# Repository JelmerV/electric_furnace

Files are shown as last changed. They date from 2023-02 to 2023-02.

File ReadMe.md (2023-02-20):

# Electronic furnace controller

This project contains the source code for the controller of an electric furnace, cad files for the enclosure, and some images of the system.

This is an arduino sketch for the controls of an electric furnace/foundry. It uses a K type thermocouple in combination with a MAX6675 IC to check the temperature inside the furnace. Current temperature and the target temperature are displayed on a small 128x64 oled display. An encoder can be used to change the target temperature. 2 relays are used to which the 220V on the heating coils. It switches both wires to ensure there is no live voltage on the coils. 2 switches are used to monitor when the lid gets lifted, in which case the voltage is immediately switched off. This is also indicated on the display by the icon of an open door. Whenever the heating elements are powered, a flaming icon is displayed.

## Wiring

The microcontroller used is an arduino nano. Both relays are controlled by a single output signal. The door switches are wired in series, using the normally closed contact. I am using a small 220vAC-5vDC converter to get the 5v for the arduino. The encoder is attached at pins 2 and 3 for external interrupts. The display uses pins A4 and A5 for SPI communication.

## Libraries

This is a platformio project, so you should be able to just open this in vs code if you have the platformio extension. If you want to use the arduino ide, then you will need to manually install the required libraries. The source code is [here](./Code/electric_furnace/src/main.cpp), and should also work as ini file. The required libraries are:

* Adafruit_GFX (for the graphics)
* Adafruit_SSD1306 (for the mini oled display)
* Adafruit max6675 (for reading the thermocouple)

## hardware

My furnace is made of firebricks and aerated concrete blocks. I used kanthal A1 wire to wind some coils totaling around 18 ohm, so at 220v it pulls around 12 amps, so 2600 Watts. THe 3d printed electronics enclosure is mounted on the side. The final system can be seen in the following image:

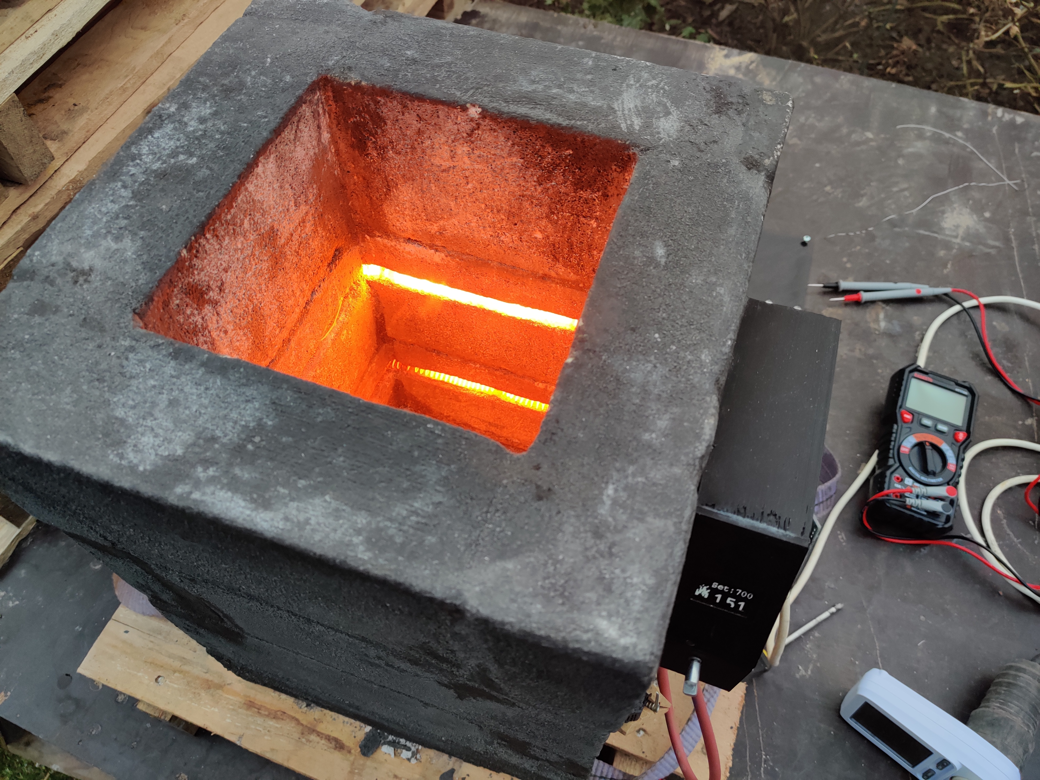
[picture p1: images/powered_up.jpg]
final system


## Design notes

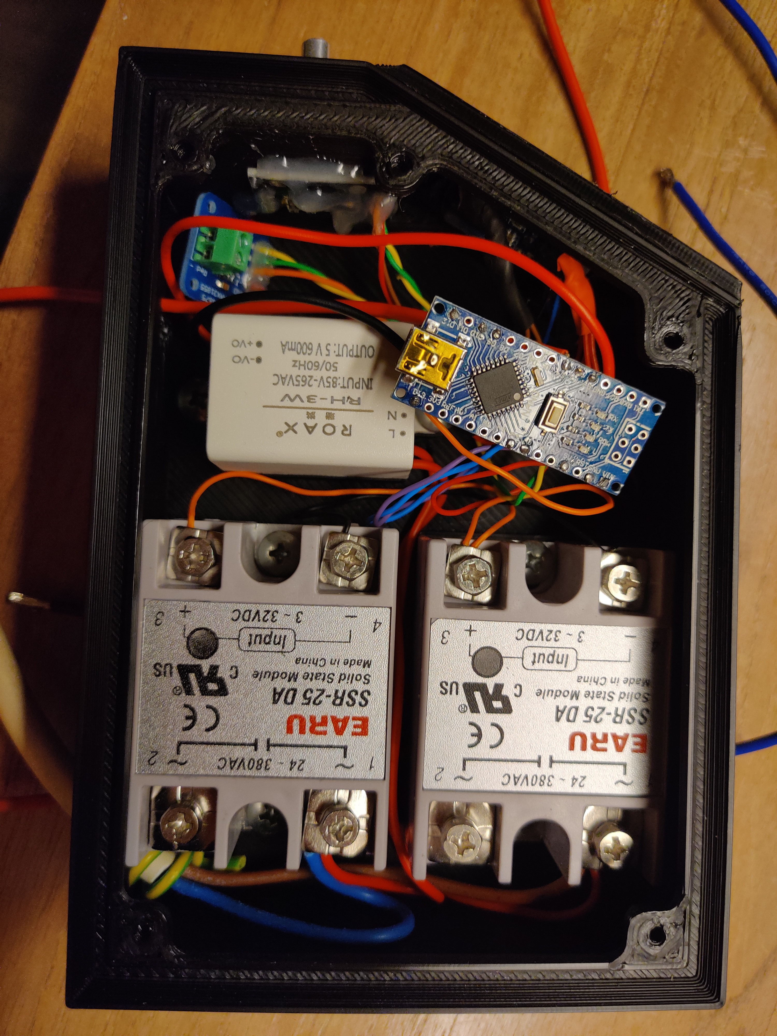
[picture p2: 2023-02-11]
images/electronics.jpg

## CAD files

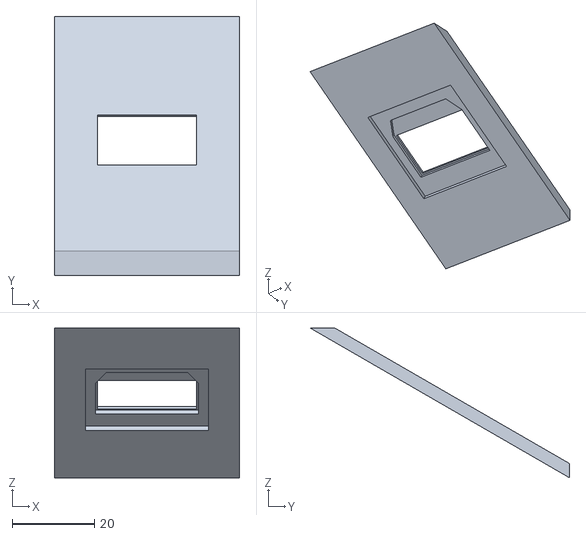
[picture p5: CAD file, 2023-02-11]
CAD/screenplate.STL
45.0 x 63.0 x 36.4

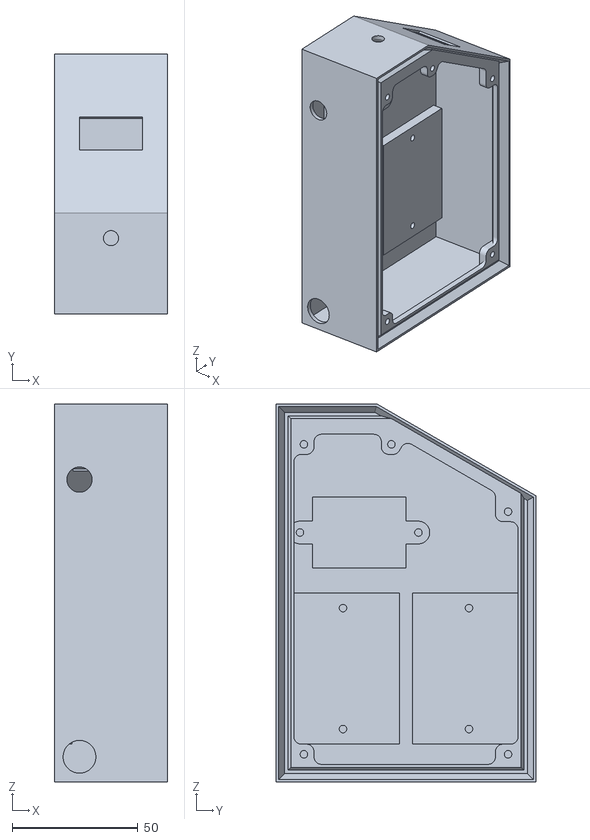
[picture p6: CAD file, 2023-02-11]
CAD/electronics box base.STL
45.0 x 103.0 x 150.0

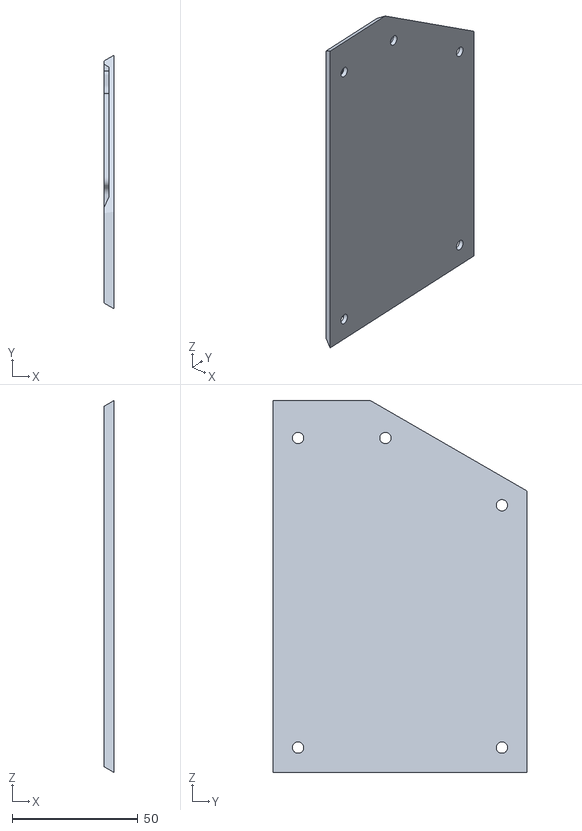
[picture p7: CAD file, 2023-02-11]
CAD/electronics box lid.STL
4.00 x 100.8 x 147.8

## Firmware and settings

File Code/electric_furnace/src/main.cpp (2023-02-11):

#include <Adafruit_GFX.h>
#include <Adafruit_SSD1306.h>
#include <Fonts/FreeMonoBold12pt7b.h>
#include <Fonts/FreeMonoBold24pt7b.h>  // Add a custom font
#include <SPI.h>
#include <Wire.h>

#include "Arduino.h"
#include "max6675.h"

// io
#define PIN_DOOR_IN 4    // Door switches input
#define PIN_COIL_OUT 13  // Coil relay control
#define PIN_ENCODER_A 2  // encoder function only works for port C, pins 0-7
#define PIN_ENCODER_B 3
#define ENCODER_PIN_MASK (1 << PIN_ENCODER_A | 1 << PIN_ENCODER_B)

// screen config
#define SCREEN_ADRESS 0x3C  // I2C address (pins A4, A5)
#define SCREEN_WIDTH 128    // OLED display width, in pixels
#define SCREEN_HEIGHT 64    // OLED display height, in pixels
#define OLED_RESET -1       // Reset pin # (or -1 if sharing Arduino reset pin)
Adafruit_SSD1306 display(SCREEN_WIDTH, SCREEN_HEIGHT, &Wire, OLED_RESET);

// thermometer config
int thermoDO = 12;
int thermoCS = 9;
int thermoCLK = 10;
MAX6675 thermocouple(thermoCLK, thermoCS, thermoDO);

// 'flame_icon', 29x43px
const unsigned char flame_icon[] PROGMEM = {
    0x00, 0x70, 0x0e, 0x00, 0x00, 0x70, 0x0e, 0x00, 0x00, 0x60, 0x0e, 0x00, 0x00, 0x01, 0xf0, 0x00, 0x00, 0x03, 0xf0, 0x00, 0x1c, 0x0f, 0xc0, 0x00, 0x1c,
    0x0f, 0xc0, 0x00, 0x1e, 0x0f, 0xc0, 0x00, 0x03, 0x83, 0xc0, 0x00, 0x03, 0x83, 0xc0, 0x00, 0x03, 0x8f, 0xf0, 0x38, 0x03, 0x8f, 0xf0, 0x38, 0x03, 0x8f,
    0xf0, 0xf8, 0x03, 0x8f, 0xf1, 0xf8, 0x03, 0x8f, 0xf1, 0xf8, 0x03, 0xff, 0xff, 0xc0, 0x03, 0xff, 0xff, 0xc0, 0x03, 0xff, 0xff, 0xc0, 0xe3, 0xfe, 0x7f,
    0xc0, 0xe3, 0xfe, 0x7f, 0xc0, 0xe3, 0xf3, 0xff, 0xc0, 0xe3, 0xf3, 0xff, 0xc0, 0xe3, 0xf3, 0xff, 0xf8, 0xe3, 0xf3, 0xcf, 0xf8, 0xf3, 0xf3, 0xcf, 0xf8,
    0xff, 0xf3, 0xf9, 0xf8, 0xff, 0xf3, 0xf9, 0xf8, 0xff, 0xf3, 0xf9, 0xf8, 0xff, 0x83, 0xf9, 0xf8, 0xff, 0x83, 0xf9, 0xf8, 0xfe, 0x00, 0x79, 0xf8, 0xfe,
    0x00, 0x79, 0xf8, 0xfe, 0x00, 0x79, 0xf8, 0xfe, 0x00, 0x01, 0xf8, 0xfe, 0x00, 0x01, 0xf8, 0xff, 0x8e, 0x0f, 0xf8, 0xff, 0x9e, 0x0f, 0xf8, 0xff, 0xff,
    0xff, 0xf8, 0x1f, 0xff, 0xff, 0xc0, 0x1f, 0xff, 0xff, 0xc0, 0x1f, 0xff, 0xff, 0xc0, 0x03, 0xff, 0xff, 0x00, 0x03, 0xff, 0xfe, 0x00};

// 'door_icon', 27x42px
const unsigned char door_icon[] PROGMEM = {
    0xff, 0xff, 0xff, 0xe0, 0xff, 0xff, 0xff, 0xe0, 0xf0, 0x00, 0x00, 0x60, 0xfc, 0x00, 0x00, 0x60, 0xff, 0x00, 0x00, 0x60, 0xff, 0xc0, 0x00, 0x60,
    0xff, 0xf8, 0x00, 0x60, 0xff, 0xfe, 0x00, 0x60, 0xff, 0xff, 0x80, 0x60, 0xff, 0xff, 0xe0, 0x60, 0xff, 0xff, 0xf8, 0x60, 0xff, 0xff, 0xf8, 0x60,
    0xff, 0xff, 0xf8, 0x60, 0xff, 0xff, 0xf8, 0x60, 0xff, 0xff, 0xf8, 0x60, 0xff, 0xff, 0xf8, 0x60, 0xff, 0xff, 0xf8, 0x60, 0xff, 0xff, 0xf8, 0x60,
    0xff, 0xff, 0xf8, 0x60, 0xff, 0xff, 0xf8, 0x60, 0xff, 0xff, 0x98, 0x60, 0xff, 0xff, 0x98, 0x60, 0xff, 0xff, 0xc8, 0x60, 0xff, 0xff, 0xc8, 0x60,
    0xff, 0xff, 0xc8, 0x60, 0xff, 0xff, 0xc8, 0x60, 0xff, 0xff, 0x98, 0x60, 0xff, 0xff, 0x98, 0x60, 0xff, 0xff, 0xf8, 0x60, 0xff, 0xff, 0xf8, 0x60,
    0xff, 0xff, 0xf8, 0x60, 0xff, 0xff, 0xf8, 0x60, 0xff, 0xff, 0xf8, 0x60, 0xff, 0xff, 0xf8, 0x60, 0x3f, 0xff, 0xf8, 0x60, 0x0f, 0xff, 0xf8, 0x60,
    0x03, 0xff, 0xf8, 0x00, 0x03, 0xff, 0xf8, 0x00, 0x00, 0xff, 0xf8, 0x00, 0x00, 0x3f, 0xf8, 0x00, 0x00, 0x0f, 0xf8, 0x00, 0x00, 0x01, 0xf8, 0x00};

// global variables
float temp_c = 0;
volatile int temp_change = 0;
int target_temp = 700;
unsigned long door_closed_millis = (2 ^ 32) - 1;
bool is_safe = false;
bool flash_door = true;

// functions
void doorInterrupt() {                      // door opened: switch off coil
    if (digitalRead(PIN_DOOR_IN) == LOW) {  // door closed: high signal
        is_safe = false;
        digitalWrite(PIN_COIL_OUT, LOW);
    } else {
        door_closed_millis = millis();
    }
}

const int encoderSteps[] = {0, -1, 1, 0, 1, 0, 0, -1, -1, 0, 0, 1, 0, 1, -1, 0};
void encoderInterrupt() {
    static uint8_t last_state;
    uint8_t state = ((PIND)&ENCODER_PIN_MASK) >> min(PIN_ENCODER_A, PIN_ENCODER_B);

    uint8_t idx = (state << 2) | last_state;  // combine 2 states into single int
    temp_change += encoderSteps[idx] * 5;     // add value at index
    last_state = state;                       // last state is current state in the lower two bits.
}

void displayTemperature(float temp_c) {
    char temp_text[5] = "1234";
    dtostrf((int)(temp_c + 0.5), 4, 0, temp_text);

    char set_text_d[5] = "1234";
    char set_text[9] = "Set:";
    dtostrf(target_temp, 3, 0, set_text_d);
    strcat(set_text, set_text_d);

    display.clearDisplay();

    display.setFont(&FreeMonoBold12pt7b);
    display.setCursor(30, 16);  // (x,y)
    display.print(set_text);    // Text or value to print

    display.setFont(&FreeMonoBold24pt7b);
    display.setCursor(15, 62);
    display.print(temp_text);  // Text or value to print

    if (!is_safe) {
        if (flash_door) {
            static bool last_door = false;
            if (last_door) {
                display.drawBitmap(2, 62 - 42, door_icon, 27, 42, 1);  // 27x42px
            }
            last_door = !last_door;
        } else {
            display.drawBitmap(2, 62 - 42, door_icon, 27, 42, 1);  // 27x42px
        }
    } else if (digitalRead(PIN_COIL_OUT)) {
        display.drawBitmap(2, 63 - 43, flame_icon, 29, 43, 1);  // 29x43
    }

    display.display();
}

void setup() {
    pinMode(PIN_DOOR_IN, INPUT_PULLUP);
    pinMode(PIN_COIL_OUT, OUTPUT);
    attachInterrupt(digitalPinToInterrupt(PIN_ENCODER_A), encoderInterrupt, CHANGE);
    attachInterrupt(digitalPinToInterrupt(PIN_ENCODER_B), encoderInterrupt, CHANGE);

    Serial.begin(115200);
    Serial.println("Electric Furnace controller");

    display.begin(SSD1306_SWITCHCAPVCC, SCREEN_ADRESS);  // start display
    display.clearDisplay();
    display.setTextColor(WHITE);
    display.cp437(true);  // Use full 256 char 'Code Page 437' font
}

void loop() {
    // read new temp
    static unsigned long last_millis = millis();
    if (millis() - last_millis >= 300) {  // For the MAX6675 minimum 250ms delay
        temp_c = thermocouple.readCelsius();
        last_millis = millis();

        Serial.print("C = ");
        Serial.println(temp_c);
        displayTemperature(temp_c);
    }

    // check if door state changed
    static bool last_door_open;
    bool door_open = digitalRead(PIN_DOOR_IN);  //pull up, normally closed to ground. pin high -> door open
    if (door_open != last_door_open) {
        if (door_open) {
            is_safe = false;
            digitalWrite(PIN_COIL_OUT, LOW);
        } else {
            door_closed_millis = millis();
        }
        last_door_open = door_open;
    }

    // check is door closed some time ago
    if (!door_open) {
        if (millis() - door_closed_millis >= 2000) {
            // delay after closing door
            is_safe = true;
            flash_door = false;
        } else if (!is_safe) {  // door closed but wait for timer
            flash_door = true;
        }
    } else {
        is_safe = false;
        flash_door = false;
    }


    // Limit temp change rate
    static unsigned long last_encoder_time = millis();
    if (millis() - last_encoder_time >= 50) {
        last_encoder_time = millis();

        int tmp = temp_change;
        temp_change = 0;

        tmp = min(20, tmp);
        tmp = max(-20, tmp);
        target_temp += tmp;
    }
    
    // cap target temp
    target_temp = min(target_temp, 995);
    target_temp = max(target_temp, 100);

    // control coil, with some hysteresis
    if (temp_c <= (target_temp)) {
        if (is_safe) {
            digitalWrite(PIN_COIL_OUT, HIGH);
        }
    } else if (temp_c > (target_temp + 20)) {  // too hot
        digitalWrite(PIN_COIL_OUT, LOW);
    }
}

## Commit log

2022-12-30 fixed encoder direction and door state
    [main.cpp]
2023-02-11 added cad, changed encoder method, fixed read rate
    [brickbase.SLDPRT, electric furnace.SLDASM, electronics box base.STL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]
2023-02-20 refactor, add cad, fix max6675 rate
    [brickbase.SLDPRT, electric furnace.SLDASM, electronics box base.STL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]
